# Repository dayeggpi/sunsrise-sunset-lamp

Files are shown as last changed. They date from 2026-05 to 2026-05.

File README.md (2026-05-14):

# sunsrise-sunset-lamp
An ESP32 S3 Zero project to build a sunrise/sunset lamp

# Web app
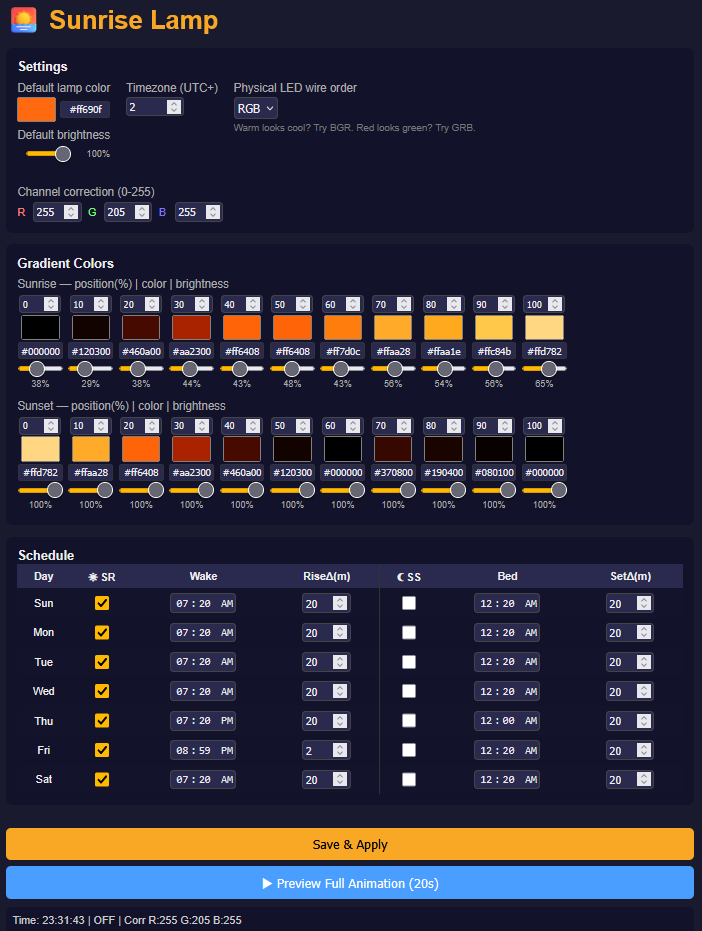
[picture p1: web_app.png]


# Lamp
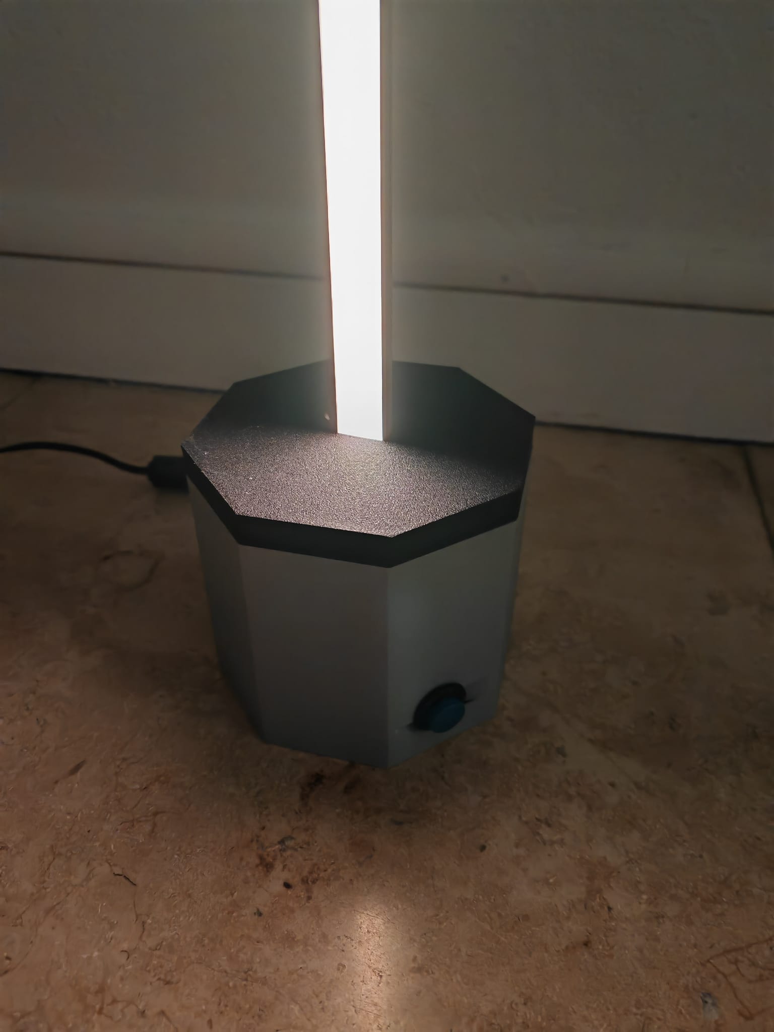
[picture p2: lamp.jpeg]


# 3D box
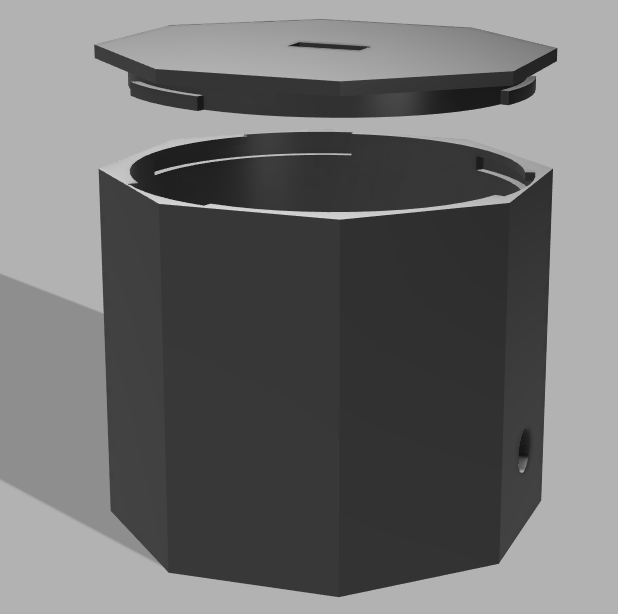
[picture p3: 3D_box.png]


# How to 

- Print the box (see in `/3D_files` folder, either the 3mf files, or adjust as per your needs using the python script in `/3D_files/Autodesk-Fusion_script`)
- Get an ESP32 S3 Zero (or equivalent)
- Compile and upload the code `sunrise_lamp.ino` to the ESP32 (don't forget to adjust the wifi SSID and password values)
- Go to your ESP32 local IP address
- Adjust the settings on the web app as needed
- Profit

# Bill of materials

- ESP 32 S3 Zero
- an LED strip and aluminum profile
- mp1584EN (or any DC-DC Step-Down 12v to 5v) : needed only if the led strip is 12v
- A push button
- a DC jack barrel

# Wiring

- Push button pin 1 goes to → ESP32 pinout 9
- Push button ping 2 goes to → ESP32 GND
- LED Strip Data In (Keep this wire as short as possible!) goes to → ESP32 Data Pin pinout 10

Following only needed if led strip is 12v :
- 12V Power + goes to → LED Strip 12V+
- 12V Power + goes to → MP1584EN IN+
- MP1584EN OUT+ (5V) goes to → ESP32 5V pin
- 12V Power GND goes to → LED Strip GND
- 12V Power GND goes to → MP1584EN IN-
- MP1584EN OUT- goes to → ESP32 GND
- (Optional but excellent for data) ESP32 GND goes to → LED Strip GND (run this wire right next to the data cable)

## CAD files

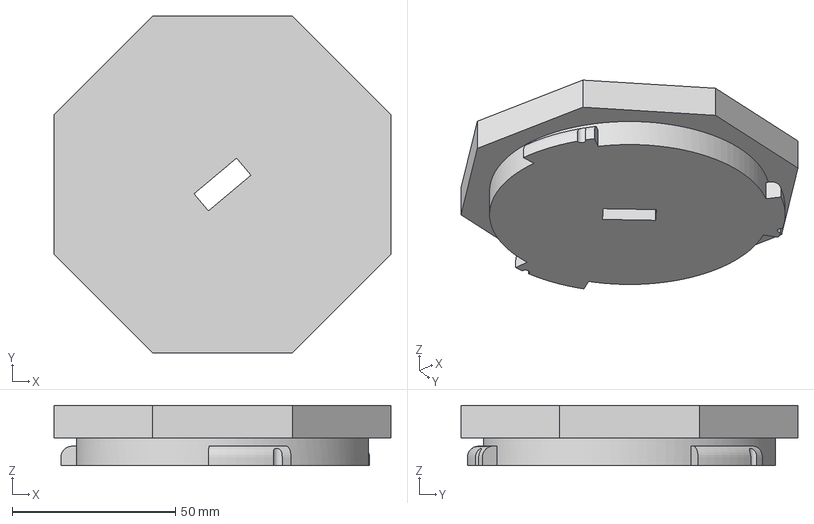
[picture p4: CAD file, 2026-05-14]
3D_files/Lid.3mf
103.2 x 103.2 x 18.5 mm

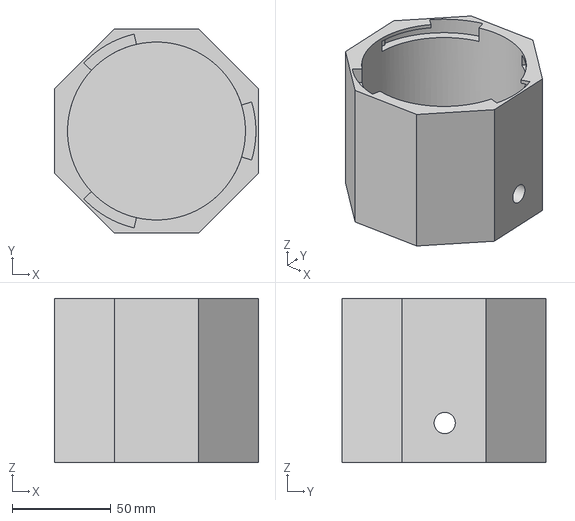
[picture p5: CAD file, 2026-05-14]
3D_files/BoxBody.3mf
103.2 x 103.2 x 83.0 mm

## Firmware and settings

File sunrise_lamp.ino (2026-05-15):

// Sunrise/Sunset Lamp — ESP32-S3 ZERO
// Requires: FastLED library (Arduino Library Manager)
//
// Adjust LED_PIN, NUM_LEDS, BUTTON_PIN for your hardware.
// Edit WIFI_SSID / WIFI_PASS below.

#include <Arduino.h>
#include <WiFi.h>
#include <WebServer.h>
#include <Preferences.h>
#include <FastLED.h>
#include <time.h>

#define LED_PIN      10
#define NUM_LEDS    288
#define LED_TYPE    WS2811
#define COLOR_ORDER RGB
#define BUTTON_PIN    9
#define NUM_STOPS    11

// ─── WiFi credentials ────────────────────────────────────────────────────────
#define WIFI_SSID "WIFI_SSID"
#define WIFI_PASS "WIFI_PASSWORD"

// ─── Types ────────────────────────────────────────────────────────────────────

struct DayConfig {
  bool    sunriseEnabled;
  bool    sunsetEnabled;
  uint8_t wakeH, wakeM;
  uint8_t bedH,  bedM;
  uint8_t sunriseDeltaMin;
  uint8_t sunsetDeltaMin;
};

enum LampState : uint8_t { S_OFF, S_ON, S_SUNRISE, S_SUNSET, S_PREVIEW };

// ─── Globals ──────────────────────────────────────────────────────────────────

WebServer   server(80);
Preferences prefs;
CRGB        leds[NUM_LEDS];

DayConfig days[7];
int8_t    tzHours         = 0;
CRGB      defaultColor(255, 215, 130);
uint8_t   defaultBrightness = 255;
bool      onAfterSunrise  = false;

uint8_t corrR = 255, corrG = 255, corrB = 255;
uint8_t   ntpIntervalHours = 3;

static const uint8_t orderTable[6][3] = {
  {0,1,2},{0,2,1},{1,0,2},{1,2,0},{2,0,1},{2,1,0}
};
static const char *orderNames[6] = {"RGB","RBG","GRB","GBR","BRG","BGR"};
uint8_t ledOrderIdx = 0;

// Gradient stops — 11 per animation, positions user-editable (0-100)
uint8_t srPos[NUM_STOPS] = {0,10,20,30,40,50,60,70,80,90,100};
uint8_t srCol[NUM_STOPS][3] = {
  {  0,  0,  0},{  8,  1,  0},{ 25,  4,  0},{ 55,  8,  0},
  {110, 20,  0},{175, 40,  2},{230, 75,  5},{255,125, 12},
  {255,170, 30},{255,200, 75},{255,215,130},
};
uint8_t srBri[NUM_STOPS] = {255,255,255,255,255,255,255,255,255,255,255};

uint8_t ssPos[NUM_STOPS] = {0,10,20,30,40,50,60,70,80,90,100};
uint8_t ssCol[NUM_STOPS][3] = {
  {255,215,130},{255,200, 75},{255,170, 30},{255,125, 12},
  {230, 75,  5},{175, 40,  2},{110, 20,  0},{ 55,  8,  0},
  { 25,  4,  0},{  8,  1,  0},{  0,  0,  0},
};
uint8_t ssBri[NUM_STOPS] = {255,255,255,255,255,255,255,255,255,255,255};

LampState lampState    = S_OFF;
bool      userControlled = false;  // user took manual control; skip auto-start until window ends
uint32_t  previewStart = 0;
bool      autoEnabled  = true;     // global kill-switch for sunrise/sunset automation
uint32_t  lastNtpSync  = 0;        // millis() of last NTP configTime call

// ─── Colour ───────────────────────────────────────────────────────────────────

static CRGB lerpRGB(CRGB a, CRGB b, float t) {
  return CRGB(
    (uint8_t)(a.r + (b.r - a.r) * t),
    (uint8_t)(a.g + (b.g - a.g) * t),
    (uint8_t)(a.b + (b.b - a.b) * t)
  );
}

static CRGB sampleGrad(uint8_t col[][3], uint8_t bri[], uint8_t pos[], float t) {
  // Before first stop
  float p0f = pos[0] / 100.0f;
  if (t <= p0f) {
    CRGB c(col[0][0], col[0][1], col[0][2]);
    c.r = (uint8_t)((uint16_t)c.r * bri[0] / 255);
    c.g = (uint8_t)((uint16_t)c.g * bri[0] / 255);
    c.b = (uint8_t)((uint16_t)c.b * bri[0] / 255);
    return c;
  }
  // Interpolate between stops
  for (int i = 0; i < NUM_STOPS - 1; i++) {
    float pa = pos[i]   / 100.0f;
    float pb = pos[i+1] / 100.0f;
    if (pb <= pa) continue;
    if (t >= pa && t <= pb) {
      float lt = (t - pa) / (pb - pa);
      CRGB c = lerpRGB(CRGB(col[i][0],col[i][1],col[i][2]),
                       CRGB(col[i+1][0],col[i+1][1],col[i+1][2]), lt);
      float lb = (float)bri[i] + (float)((int)bri[i+1] - (int)bri[i]) * lt;
      uint8_t b = (uint8_t)constrain((int)lb, 0, 255);
      c.r = (uint8_t)((uint16_t)c.r * b / 255);
      c.g = (uint8_t)((uint16_t)c.g * b / 255);
      c.b = (uint8_t)((uint16_t)c.b * b / 255);
      return c;
    }
  }
  // After last stop
  CRGB last(col[NUM_STOPS-1][0], col[NUM_STOPS-1][1], col[NUM_STOPS-1][2]);
  last.r = (uint8_t)((uint16_t)last.r * bri[NUM_STOPS-1] / 255);
  last.g = (uint8_t)((uint16_t)last.g * bri[NUM_STOPS-1] / 255);
  last.b = (uint8_t)((uint16_t)last.b * bri[NUM_STOPS-1] / 255);
  return last;
}

static CRGB sunriseColor(float t) { return sampleGrad(srCol, srBri, srPos, t); }
static CRGB sunsetColor(float t)  { return sampleGrad(ssCol, ssBri, ssPos, t); }

// Applies logical correction then physical wire reorder.
static CRGB toWire(CRGB c) {
  c.r = (uint8_t)((uint16_t)c.r * corrR / 255);
  c.g = (uint8_t)((uint16_t)c.g * corrG / 255);
  c.b = (uint8_t)((uint16_t)c.b * corrB / 255);
  uint8_t ch[3] = {c.r, c.g, c.b};
  const uint8_t *o = orderTable[ledOrderIdx];
  return CRGB(ch[o[0]], ch[o[1]], ch[o[2]]);
}

// ─── Time helpers ─────────────────────────────────────────────────────────────

static struct tm nowTm() {
  time_t now = time(nullptr);
  struct tm t = {};
  localtime_r(&now, &t);
  return t;
}

static bool inDeltaWindow(bool *sunrise, float *progress) {
  if (!autoEnabled) return false;
  struct tm  t = nowTm();
  DayConfig &d = days[t.tm_wday];
  int now  = t.tm_hour * 3600 + t.tm_min * 60 + t.tm_sec;
  int wake = (d.wakeH * 60 + d.wakeM) * 60;
  int bed  = (d.bedH  * 60 + d.bedM ) * 60;
  if (d.sunriseEnabled && d.sunriseDeltaMin > 0) {
    int dSec = d.sunriseDeltaMin * 60;
    if (now >= wake - dSec && now < wake) {
      *sunrise  = true;
      *progress = float(now - (wake - dSec)) / dSec;
      return true;
    }
  }
  if (d.sunsetEnabled && d.sunsetDeltaMin > 0) {
    int dSec = d.sunsetDeltaMin * 60;
    if (now >= bed - dSec && now < bed) {
      *sunrise  = false;
      *progress = float(now - (bed - dSec)) / dSec;
      return true;
    }
  }
  return false;
}

// ─── Persistent storage ───────────────────────────────────────────────────────

static void loadSettings() {
  prefs.begin("lamp", true);
  autoEnabled = prefs.getBool("auto", true);
  tzHours = prefs.getChar("tz", 0);

  uint8_t dc[3] = {255, 215, 130};
  prefs.getBytes("defcol", dc, 3);
  defaultColor      = CRGB(dc[0], dc[1], dc[2]);
  defaultBrightness = (uint8_t)prefs.getChar("dbri", (int8_t)255);

  uint8_t cr[3] = {255, 255, 255};
  prefs.getBytes("corr", cr, 3);
  corrR = cr[0]; corrG = cr[1]; corrB = cr[2];

  ledOrderIdx = (uint8_t)constrain((int)prefs.getChar("ordi", 0), 0, 5);
  ntpIntervalHours = (uint8_t)constrain((int)prefs.getUChar("ntpiv", 3), 1, 168);

  prefs.getBytes("srpos", srPos, sizeof(srPos));
  prefs.getBytes("srcol", srCol, sizeof(srCol));
  prefs.getBytes("srbri", srBri, sizeof(srBri));
  prefs.getBytes("sspos", ssPos, sizeof(ssPos));
  prefs.getBytes("sscol", ssCol, sizeof(ssCol));
  prefs.getBytes("ssbri", ssBri, sizeof(ssBri));

  for (int i = 0; i < 7; i++) {
    char k[4]; snprintf(k, sizeof(k), "d%d", i);
    uint8_t b[8] = {1, 1, 7, 0, 22, 0, 20, 20};
    prefs.getBytes(k, b, 8);
    days[i] = {(bool)b[0], (bool)b[1], b[2], b[3], b[4], b[5], b[6], b[7]};
  }
  prefs.end();
}

static void saveSettings() {
  prefs.begin("lamp", false);
  prefs.putBool("auto", autoEnabled);
  prefs.putChar("tz", tzHours);

  uint8_t dc[3] = {defaultColor.r, defaultColor.g, defaultColor.b};
  prefs.putBytes("defcol", dc, 3);
  prefs.putChar("dbri", (int8_t)defaultBrightness);

  uint8_t cr[3] = {corrR, corrG, corrB};
  prefs.putBytes("corr", cr, 3);
  prefs.putChar("ordi", (int8_t)ledOrderIdx);
  prefs.putUChar("ntpiv", ntpIntervalHours);

  prefs.putBytes("srpos", srPos, sizeof(srPos));
  prefs.putBytes("srcol", srCol, sizeof(srCol));
  prefs.putBytes("srbri", srBri, sizeof(srBri));
  prefs.putBytes("sspos", ssPos, sizeof(ssPos));
  prefs.putBytes("sscol", ssCol, sizeof(ssCol));
  prefs.putBytes("ssbri", ssBri, sizeof(ssBri));

  for (int i = 0; i < 7; i++) {
    char k[4]; snprintf(k, sizeof(k), "d%d", i);
    uint8_t b[8] = {days[i].sunriseEnabled, days[i].sunsetEnabled,
                    days[i].wakeH,          days[i].wakeM,
                    days[i].bedH,           days[i].bedM,
                    days[i].sunriseDeltaMin, days[i].sunsetDeltaMin};
    prefs.putBytes(k, b, 8);
  }
  prefs.end();
}

// ─── Button ───────────────────────────────────────────────────────────────────

static void onPress() {
  if (lampState == S_PREVIEW) { lampState = S_OFF; return; }

  bool sr; float prog;
  bool inW = inDeltaWindow(&sr, &prog);

  if (!inW || userControlled) {
    // Simple toggle — user is in control
    if (lampState == S_OFF) {
      lampState       = S_ON;
      onAfterSunrise  = false;
    } else {
      lampState = S_OFF;
    }
    if (!inW) userControlled = false;  // leaving delta: reset for next window
  } else {
    // Inside delta, automation was running (or lamp was manually on) — take manual control
    lampState      = S_OFF;
    userControlled = true;
  }
}

static void handleButton() {
  static bool     stable  = HIGH;
  static bool     prev    = HIGH;
  static uint32_t lastChg = 0;
  bool cur = digitalRead(BUTTON_PIN);
  if (cur != stable) { stable = cur; lastChg = millis(); }
  if (millis() - lastChg > 50) {
    if (stable == LOW && prev == HIGH) onPress();
    prev = stable;
  }
}

// ─── Lamp update ──────────────────────────────────────────────────────────────

static void updateLamp() {
  CRGB col;

  if (lampState == S_PREVIEW) {
    float t = float(millis() - previewStart) / 20000.0f;
    if (t >= 1.0f)     { lampState = S_OFF; col = CRGB::Black; }
    else if (t < 0.5f) { col = sunriseColor(t * 2.0f); }
    else               { col = sunsetColor((t - 0.5f) * 2.0f); }
    fill_solid(leds, NUM_LEDS, toWire(col));
    FastLED.show();
    return;
  }

  bool sr; float prog;
  bool inW = inDeltaWindow(&sr, &prog);

  if (!inW) {
    userControlled = false;  // delta ended: re-enable automation for next window
    if      (lampState == S_SUNRISE) { onAfterSunrise = true;  lampState = S_ON;  }
    else if (lampState == S_SUNSET)  {                          lampState = S_OFF; }
  }

  if (inW && !userControlled) {
    // Auto-start sunrise: only from OFF
    if (sr && lampState == S_OFF)
      lampState = S_SUNRISE;
    // Auto-start sunset: from OFF, or from ON only if lamp came from a sunrise (not manual)
    if (!sr && (lampState == S_OFF || (lampState == S_ON && onAfterSunrise)))
      lampState = S_SUNSET;
  }

  switch (lampState) {
    case S_OFF:
      col = CRGB::Black;
      break;
    case S_ON:
      if (onAfterSunrise) {
        col = sunriseColor(1.0f);          // gradient endpoint color
      } else {
        col = defaultColor;
        col.r = (uint8_t)((uint16_t)col.r * defaultBrightness / 255);
        col.g = (uint8_t)((uint16_t)col.g * defaultBrightness / 255);
        col.b = (uint8_t)((uint16_t)col.b * defaultBrightness / 255);
      }
      break;
    case S_SUNRISE: col = sunriseColor(prog); break;
    case S_SUNSET:  col = sunsetColor(prog);  break;
    default:        col = CRGB::Black;        break;
  }
  fill_solid(leds, NUM_LEDS, toWire(col));
  FastLED.show();
}

// ─── Web server helpers ───────────────────────────────────────────────────────

static void parseHexColor(const String &h, uint8_t *r, uint8_t *g, uint8_t *b) {
  if (h.length() == 7 && h[0] == '#') {
    *r = (uint8_t)strtol(h.substring(1,3).c_str(), NULL, 16);
    *g = (uint8_t)strtol(h.substring(3,5).c_str(), NULL, 16);
    *b = (uint8_t)strtol(h.substring(5,7).c_str(), NULL, 16);
  }
}

static String toHex(uint8_t r, uint8_t g, uint8_t b) {
  char buf[8];
  snprintf(buf, sizeof(buf), "#%02x%02x%02x", r, g, b);
  return String(buf);
}

// Appends one gradient stop: position input, color picker, hex input, brightness slider.
static void appendStop(String &body, int i,
                        const char *pfxC, const char *pfxH,
                        const char *pfxB, const char *pfxV, const char *pfxP,
                        const char *nameC, const char *nameB, const char *nameP,
                        uint8_t r, uint8_t g, uint8_t b, uint8_t bri, uint8_t pos) {
  String hx = toHex(r, g, b);
  int    bp = (int)bri * 100 / 255;
  String ci = String(pfxC) + i;
  String hi = String(pfxH) + i;
  String bi = String(pfxB) + i;
  String vi = String(pfxV) + i;
  // Position input
  body += F("<div class=gs>");
  body += F("<input type=number name="); body += nameP; body += i;
  body += F(" min=0 max=100 value="); body += pos;
  body += F(" style='width:44px;font-size:.72em;margin-bottom:2px'>");
  // Color swatch + hidden color input
  String si = String("W") + String(pfxC).substring(1) + i;
  body += F("<div id="); body += si;
  body += F(" class=sw style='background:"); body += hx;
  body += F("' onclick='openCP(\""); body += ci; body += F("\",\""); body += hi; body += F("\",\""); body += si; body += F("\")'></div>");
  body += F("<input type=color id="); body += ci;
  body += F(" name="); body += nameC; body += i;
  body += F(" value='"); body += hx; body += F("'>");
  body += F("<input type=text id="); body += hi;
  body += F(" value='"); body += hx;
  body += F("' maxlength=7 onchange='sc(\""); body += hi; body += F("\",\""); body += ci; body += F("\",\""); body += si; body += F("\")'>");
  // Brightness
  body += F("<input type=range id="); body += bi;
  body += F(" name="); body += nameB; body += i;
  body += F(" min=0 max=255 value="); body += bri;
  body += F(" oninput='sb(\""); body += bi; body += F("\",\""); body += vi; body += F("\")'>");
  body += F("<span id="); body += vi; body += F(" class=pct>"); body += bp; body += F("%</span>");
  body += F("</div>");
}

// ─── Web handlers ─────────────────────────────────────────────────────────────

static void handleRoot() {
  static const char *DN[] = {"Sun","Mon","Tue","Wed","Thu","Fri","Sat"};

  String body;
  body.reserve(22000);
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
void loop() {
  server.handleClient();
  handleButton();
  updateLamp();
  if (WiFi.status() == WL_CONNECTED && millis() - lastNtpSync >= (unsigned long)ntpIntervalHours * 3600000UL) {
    configTime(tzHours * 3600, 0, "pool.ntp.org");
    lastNtpSync = millis();
  }
  delay(100);
}
